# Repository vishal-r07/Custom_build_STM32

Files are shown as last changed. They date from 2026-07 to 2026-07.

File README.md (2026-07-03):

# Customized STM32 Development Board

**Designer:** Vishal Meyyappan R
**Design Tool:** KiCad 9.0
**MCU:** STM32F103C8T6 (LQFP-48)

A compact, breakout-style STM32F103 development board built around a "Blue Pill"-class microcontroller, with dual power input (USB or barrel jack), onboard microSD storage for data logging, and broken-out USART/I2C/SWD headers for peripherals and debugging.

---

## 1. Overview

This board is designed as a general-purpose sensor data acquisition and logging platform. The core idea: read sensor values over I2C or USART, and persist them to a microSD card in real time, so the board can operate as a standalone data logger without needing a permanent connection to a PC. It can be powered either from USB (during development/debugging) or from an external DC supply via the barrel jack (for field/standalone deployment), with both sources safely combined so either one can be present without conflict.

### Key features

- STM32F103C8T6 microcontroller — 72 MHz Cortex-M3, 64KB Flash, 20KB RAM
- Dual power input: USB Micro-B **or** 7–12V DC barrel jack, diode-ORed together
- Onboard AMS1117-3.3 LDO regulator (3.3V logic/power rail)
- microSD card slot (SPI mode) for onboard data storage/logging
- USART1 header for serial communication (e.g. GPS, external logger, PC terminal)
- I2C2 header for sensor peripherals (IMUs, environmental sensors, RTCs, displays, etc.)
- SWD header for programming and debugging (ST-Link compatible)
- Reset button and status LED
- USB D+/D- routed directly to the MCU for native USB device applications (e.g. CDC virtual COM port, DFU bootloader use)
- 4x M2 mounting holes for mechanical enclosure mounting

---

## 2. Functional Blocks

### 2.1 Power Supply

The board accepts power from **either** of two sources, which are combined onto a single protected rail before regulation:

| Source | Connector | Voltage | Notes |
|---|---|---|---|
| USB | J1 (USB Micro-B) | 5V (VBUS) | Also carries D+/D- to the MCU for USB device functionality |
| DC Barrel Jack | J5 | 7–12V (typical wall adapter) | Center pin positive |

Both inputs pass through a dedicated Schottky diode (D2 for the barrel jack, D3 for USB VBUS) before joining onto a common rail. This "power-ORing" arrangement means:
- Either source can be connected and power the board independently.
- If both are connected simultaneously, the board draws from whichever is at the higher potential, without one source backfeeding into the other's connector — protecting a USB host (like a laptop) from being driven by the barrel jack supply, and vice versa.
- Reverse-polarity protection is inherent: if the barrel jack is wired backwards, the diode simply blocks conduction rather than damaging the board.

The combined rail feeds **U2 (AMS1117-3.3)**, a linear regulator that steps the input down to a clean 3.3V rail (`+3.3V`), which powers the MCU core, I/O, and the microSD card. `FB1` (a 120Ω ferrite bead) filters high-frequency noise on the USB VBUS path specifically, and `D1` (LED) with `R3` provides a visual power-on indicator.

A separate `+3.3VA` net is also present for the MCU's analog supply (`VDDA`), isolated with `C7`/`C8` to reduce noise coupling into the ADC/analog peripherals from the digital 3.3V rail.

### 2.2 Microcontroller (U1 — STM32F103C8T6)

The MCU is clocked from an 8 MHz external crystal (`Y1`, `Crystal_GND24`) with `C10`/`C11` (10pF) load capacitors, feeding the HSE (High-Speed External) oscillator input. `SW1` provides a manual reset (NRST), debounced by `C9` and pulled up by `R1`.

Boot mode selection (`BOOT0`) is available on the board for entering the built-in USB/UART bootloader if needed, alongside the SWD interface for hardware debugging.

### 2.3 USB Interface (J1)

A USB Micro-B connector routes `D+`/`D-` directly to the MCU's native USB peripheral pins (`PA11`/`PA12`), enabling USB device applications such as a virtual COM port (CDC), custom HID device, or DFU firmware updates. `R2` (1.5kΩ) pulls `USB_D-` up to 3.3V, a common requirement for the MCU to be recognized as a full-speed USB device without needing to bit-bang the pull-up in firmware.

### 2.4 DC Barrel Jack Input (J5)

For standalone/field operation where USB isn't available (e.g. powered by a wall adapter or battery pack), `J5` accepts a standard center-positive barrel connector. `C14`/`C15` provide bulk and high-frequency decoupling right at the input before the reverse-polarity diode `D2`.

### 2.5 microSD Card Storage (J6)

This is the board's primary logging mechanism. The microSD slot is wired in **SPI mode** (rather than native 4-bit SD mode, which this MCU's hardware doesn't support), using the MCU's SPI1 peripheral:

| J6 Pin | Native SD Function | SPI Mode Function | STM32 Pin |
|---|---|---|---|
| 2 (DAT3/CD) | Data line 3 / Card Detect | Chip Select (CS) | PA4 |
| 3 (CMD) | Command line | MOSI (DI) | PA7 |
| 5 (CLK) | Clock | SCK | PA5 |
| 7 (DAT0) | Data line 0 | MISO (DO) | PA6 |
| 1 (DAT2), 8 (DAT1) | Data lines 1–2 | Unused in SPI mode | Pulled up to 3.3V (R6–R8) |
| 4 (VDD) | Power | Power | +3.3V |
| 6 (VSS) | Ground | Ground | GND |
| 9 (SHIELD) | — | Mechanical shield | GND |

`C16` (100nF) decouples the card's local supply. A pull-up on `CS` (`PA4`) ensures the card remains deselected during MCU power-up/reset, before firmware has configured the pin as an active output — preventing bus contention during boot.

**Intended use case:** the board reads sensor data (e.g. from a device on the I2C2 header) at a fixed interval, formats it (e.g. as a CSV row with a timestamp), and writes it to a file on the SD card using a FAT filesystem library (FatFs) running over this SPI interface. This lets the board function as a self-contained data logger — sensor readings accumulate on the card over time and can be retrieved simply by removing the card and reading it on a PC, without needing a live connection to the board.

### 2.6 Communication Headers

| Header | Signals | Typical Use |
|---|---|---|
| J2 | SWDIO, SWCLK, 3.3V, GND | Programming/debugging via ST-Link or compatible SWD probe |
| J3 | USART1_TX, USART1_RX, 3.3V, GND | Serial communication — external modules (GPS, Bluetooth/BLE, PC terminal), or a second logging path |
| J4 | I2C2_SCL, I2C2_SDA, 3.3V, GND | Sensor peripherals — IMUs, environmental sensors (temperature/humidity/pressure), RTCs, OLED displays, etc. |

`R4`/`R5` (1.5kΩ) provide I2C bus pull-ups on the SDA/SCL lines.

### 2.7 Status & Control

- `D1` (LED) — power-on indicator, active whenever the 3.3V rail is present
- `SW1` — manual reset button (NRST)

### 2.8 Mechanical

Four M2 mounting holes (`H1`–`H4`) are provided at the board corners for enclosure mounting.

---

## 3. Typical Application: Sensor Data Logger

A representative use case this board is designed around:

1. Connect a sensor (e.g. an I2C temperature/humidity sensor, or an IMU) to the **J4 (I2C2)** header.
2. Firmware on the STM32 periodically polls the sensor over I2C.
3. Each reading is timestamped and formatted as a line of text (e.g. CSV: `timestamp,value1,value2`).
4. The line is written to a log file on the microSD card via **SPI1 + FatFs**.
5. The card can be removed and read on any PC, or the board can optionally stream the same data live over **J3 (USART1)** for real-time monitoring during development.

This makes the board suitable for applications like environmental monitoring stations, unattended data collection, portable measurement tools, or any project needing local, non-volatile storage of time-series sensor data without relying on cloud connectivity.

---

## 4. Power Architecture Summary

```
USB Micro-B (5V)  ──▶ D3 ──┐
                            ├──▶ Shared VIN net ──▶ AMS1117-3.3 (U2) ──▶ +3.3V rail ──▶ MCU, SD card, peripherals
Barrel Jack (7-12V) ─▶ D2 ──┘
```

Both sources are diode-ORed so either can power the board independently; the AMS1117-3.3 regulates whichever is present down to a clean 3.3V for the rest of the system.

---

## 5. Bill of Materials

| Reference | Qty | Value | Footprint | Datasheet |
|---|---|---|---|---|
| C1, C2, C3, C4, C9, C15, C16 | 7 | 100n | Capacitor_SMD:C_0402_1005Metric | ~ |
| C5, C14 | 2 | 10u | Capacitor_SMD:C_0603_1608Metric | ~ |
| C6 | 1 | 10n | Capacitor_SMD:C_0402_1005Metric | ~ |
| C7, C8 | 2 | 1u | Capacitor_SMD:C_0402_1005Metric | ~ |
| C10, C11 | 2 | 10p | Capacitor_SMD:C_0402_1005Metric | ~ |
| C12, C13 | 2 | 22u | Capacitor_SMD:C_0805_2012Metric | ~ |
| D1 | 1 | LED | LED_SMD:LED_0603_1608Metric | ~ |
| D2, D3 | 2 | D_Schottky | Diode_SMD:D_SMA | ~ |
| FB1 | 1 | 120R | Inductor_SMD:L_0603_1608Metric | ~ |
| H1, H2, H3, H4 | 4 | MountingHole | MountingHole:MountingHole_2.2mm_M2 | ~ |
| J1 | 1 | USB_B_Micro | Connector_USB:USB_Micro-B_Wuerth_629105150521 | ~ |
| J2, J3, J4 | 3 | Conn_01x04_Pin | Connector_PinSocket_2.54mm:PinSocket_1x04_P2.54mm_Vertical | ~ |
| J5 | 1 | Barrel_Jack | Connector_BarrelJack:BarrelJack_Horizontal | ~ |
| J6 | 1 | Micro_SD_Card | Connector_Card:microSD_HC_Wuerth_693072010801 | [Datasheet](https://www.we-online.com/components/products/datasheet/693072010801.pdf) |
| R1 | 1 | 10K | Resistor_SMD:R_0402_1005Metric | ~ |
| R2, R3, R4, R5 | 4 | 1k5 | Resistor_SMD:R_0402_1005Metric | ~ |
| R6, R7, R8 | 3 | 10k | Resistor_SMD:R_0402_1005Metric | ~ |
| SW1 | 1 | SW_SPDT | Button_Switch_SMD:SW_SPDT_PCM12 | ~ |
| U1 | 1 | STM32F103C8Tx | Package_QFP:LQFP-48_7x7mm_P0.5mm | [Datasheet](https://www.st.com/resource/en/datasheet/stm32f103c8.pdf) |
| U2 | 1 | AMS1117-3.3 | Package_TO_SOT_SMD:SOT-223-3_TabPin2 | [Datasheet](http://www.advanced-monolithic.com/pdf/ds1117.pdf) |
| Y1 | 1 | Crystal_GND24 | Crystal:Crystal_SMD_3225-4Pin_3.2x2.5mm | ~ |

**Total unique references:** 24 | **Total placed components:** ~50 (excluding mounting holes)

---

## 6. Firmware Notes

- **Toolchain:** STM32CubeIDE (or STM32CubeMX + preferred IDE/toolchain)
- **SD card access:** SPI1 peripheral + FatFs middleware (SD-over-SPI driver); recommend low clock speed (~400 kHz) during card initialization, then increasing to a few MHz for normal read/write operations
- **I2C sensor communication:** I2C2 peripheral (`PB10`/`PB11`), 3.3V logic
- **Serial/debug output:** USART1 (`PA9`/`PA10`), standard TTL-level UART, 3.3V logic
- **Debugging:** Standard SWD (`PA13`/`PA14`) — compatible with ST-Link V2/V3 or any SWD-capable probe
- **USB:** Native USB device peripheral (`PA11`/`PA12`) — usable for CDC virtual COM port, custom HID, or DFU bootloader entry

---



**PCB Editor**



**3D VIEW**

I have attached Schematic sheet as output.pdf

---

## Designed by Vishal Meyyappan R

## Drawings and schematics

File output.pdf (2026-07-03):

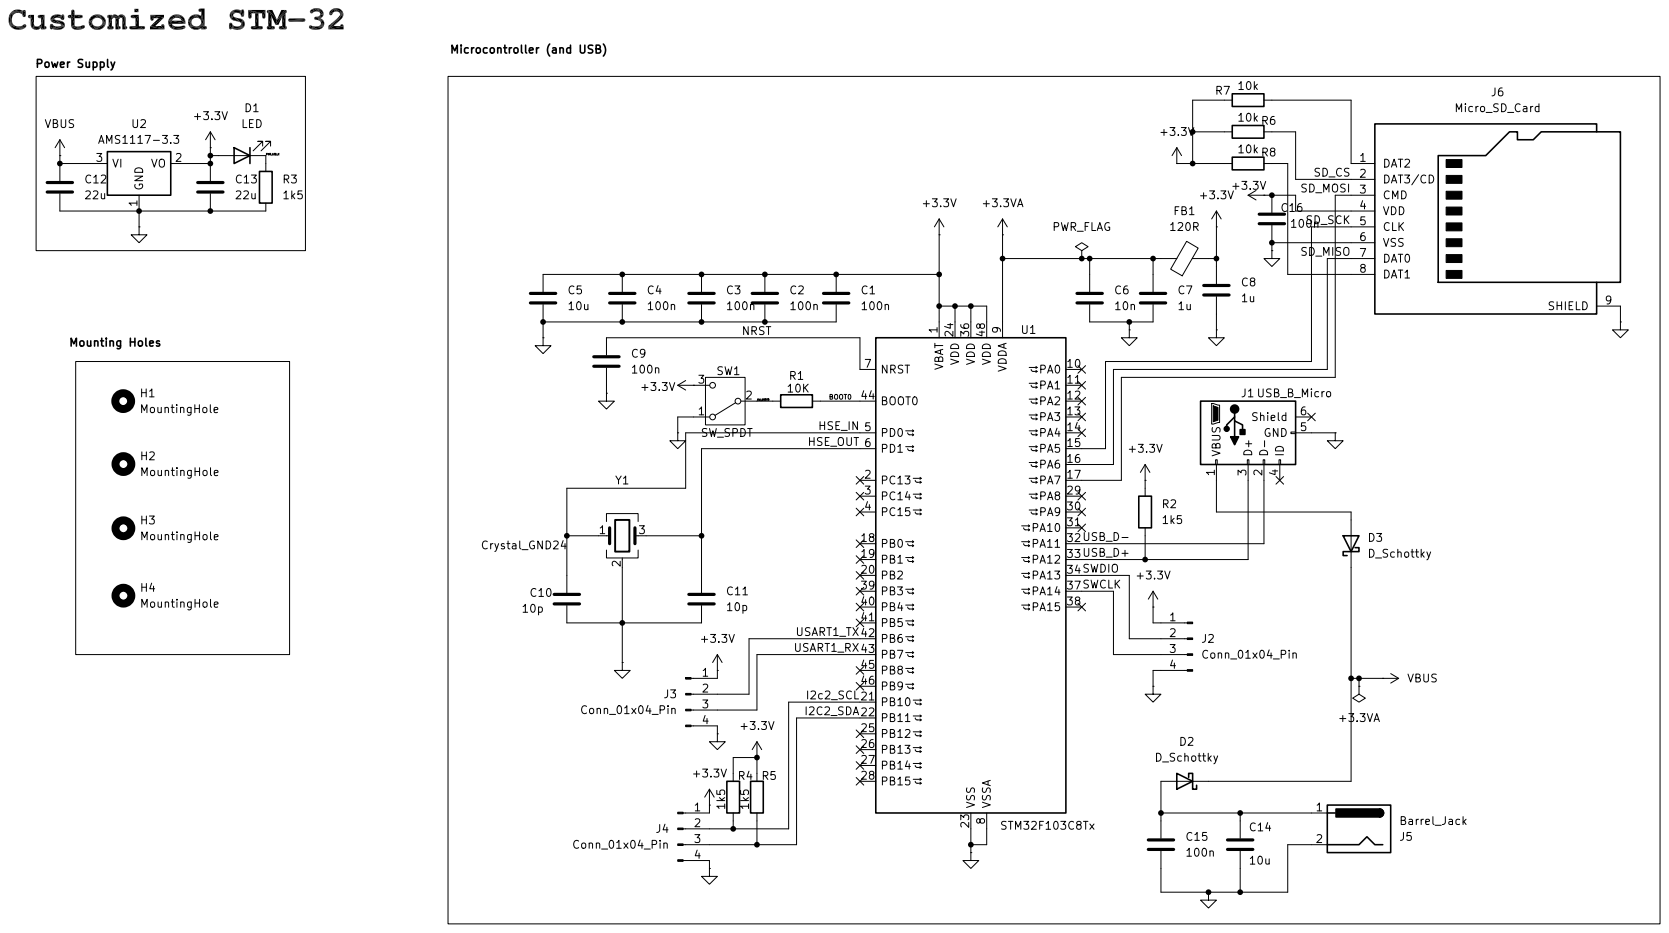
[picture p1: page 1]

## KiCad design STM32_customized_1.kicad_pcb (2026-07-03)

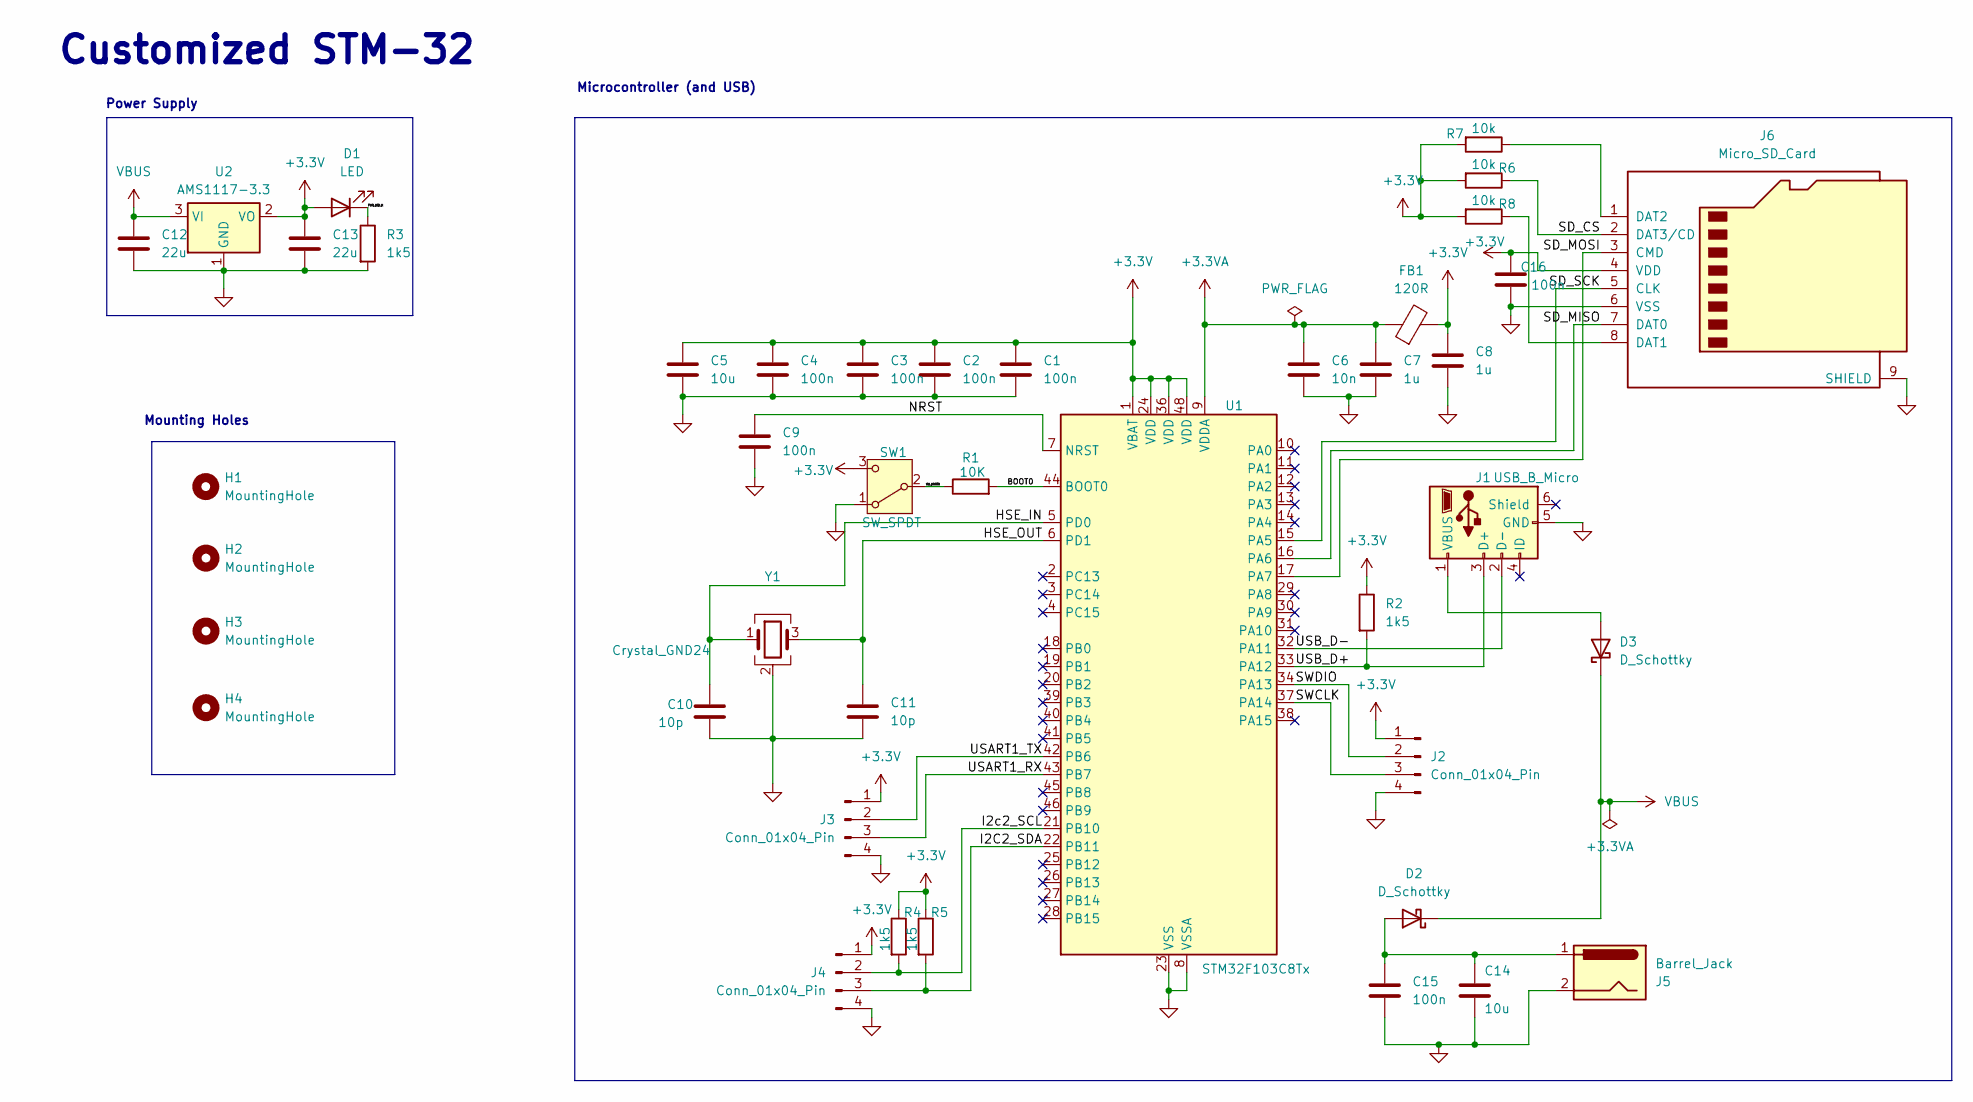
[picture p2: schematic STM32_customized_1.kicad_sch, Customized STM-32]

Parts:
C1, C2, C3, C4, C9, C15, C16: 100n; C_0402_1005Metric
C5, C14: 10u; C_0603_1608Metric
C6: 10n; C_0402_1005Metric
C7, C8: 1u; C_0402_1005Metric
C10, C11: 10p; C_0402_1005Metric
C12, C13: 22u; C_0805_2012Metric
D1: LED; LED_0603_1608Metric
D2, D3: D_Schottky; D_SMA
FB1: 120R; L_0603_1608Metric
H1, H2, H3, H4: MountingHole; MountingHole_2.2mm_M2
J1: USB_B_Micro; USB_Micro-B_Wuerth_629105150521
J2, J3, J4: Conn_01x04_Pin; PinSocket_1x04_P2.54mm_Vertical
J5: Barrel_Jack; BarrelJack_Horizontal
J6: Micro_SD_Card; microSD_HC_Wuerth_693072010801
R1: 10K; R_0402_1005Metric
R2, R3, R4, R5: 1k5; R_0402_1005Metric
R6, R7, R8: 10k; R_0402_1005Metric
SW1: SW_SPDT; SW_SPDT_PCM12
U1: STM32F103C8Tx; LQFP-48_7x7mm_P0.5mm
U2: AMS1117-3.3; SOT-223-3_TabPin2
Y1: Crystal_GND24; Crystal_SMD_3225-4Pin_3.2x2.5mm

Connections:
+3.3V: C1.1, C2.1, C3.1, C4.1, C5.1, C8.1, C13.1, C16.1, D1.2 (A), FB1.2, J2.1, J3.1, J4.1, J6.4 (VDD), R2.1, R4.1, R5.1, R6.2, R7.2, R8.2, SW1.3 (C), U1.1 (VBAT), U1.24 (VDD), U1.36 (VDD), U1.48 (VDD), U2.2 (VO)
+3.3VA: C6.1, C7.1, FB1.1, U1.9 (VDDA)
/BOOT0: R1.2, U1.44 (BOOT0)
/HSE_IN: C10.1, U1.5 (PD0), Y1.1
/HSE_OUT: C11.1, U1.6 (PD1), Y1.3
/I2C2_SDA: J4.3, R5.2, U1.22 (PB11)
/I2c2_SCL: J4.2, R4.2, U1.21 (PB10)
/NRST: C9.1, U1.7 (NRST)
/PWR_LED_K: D1.1 (K), R3.1
/SD_CS: J6.2 (DAT3/CD), R6.1
/SD_MISO: J6.7 (DAT0), U1.16 (PA6)
/SD_MOSI: J6.3 (CMD), U1.17 (PA7)
/SD_SCK: J6.5 (CLK), U1.15 (PA5)
/SWCLK: J2.3, U1.37 (PA14)
/SWDIO: J2.2, U1.34 (PA13)
/SW_BOOT0: R1.1, SW1.2 (B)
/USART1_RX: J3.3, U1.43 (PB7)
/USART1_TX: J3.2, U1.42 (PB6)
/USB_D+: J1.3 (D+), R2.2, U1.33 (PA12)
/USB_D-: J1.2 (D-), U1.32 (PA11)
GND: C1.2, C2.2, C3.2, C4.2, C5.2, C6.2, C7.2, C8.2, C9.2, C10.2, C11.2, C12.2, C13.2, C14.2, C15.2, C16.2, J1.5 (GND), J2.4, J3.4, J4.4, J5.2, J6.6 (VSS), J6.9 (SHIELD), R3.2, SW1.1 (A), U1.8 (VSSA), U1.23 (VSS), U1.35 (VSS), U1.47 (VSS), U2.1 (GND), Y1.2 (G), Y1.4 (G)
unnamed: C14.1, C15.1, D2.2 (A), J5.1
unnamed: D3.2 (A), J1.1 (VBUS)
unnamed: J6.8 (DAT1), R8.1
unnamed: J6.1 (DAT2), R7.1
VBUS: C12.1, D2.1 (K), D3.1 (K), U2.3 (VI)

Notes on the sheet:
Mounting Holes
Microcontroller (and USB)
Power Supply
Customized STM-32

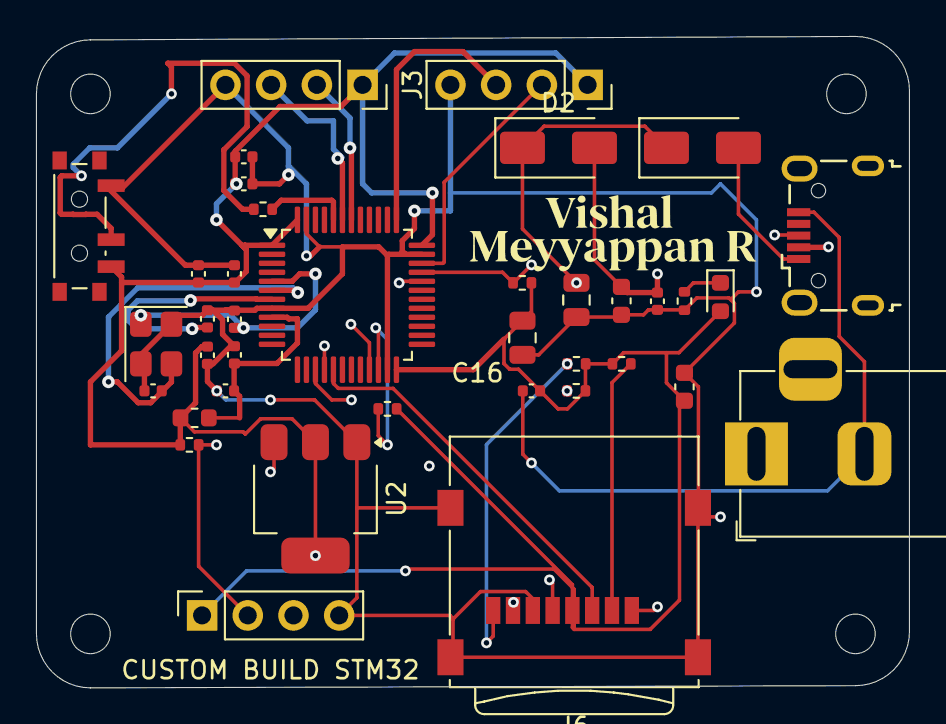
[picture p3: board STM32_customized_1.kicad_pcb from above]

Board: 4 copper layers, 48.5 x 36.2 mm, 42 parts (0 on the bottom side), 26 nets.

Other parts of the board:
CUSTOM BUILD STM32: MountingHole; MountingHole_2.2mm_M2

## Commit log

2026-07-03 Enhance README with functional specifications and guides
    Expanded the README to include detailed functional specifications, application guides, and implementation workflows for the customized STM32F103C8Tx development board.
2026-07-03 Revise README for improved documentation and clarity
    Updated the README to enhance clarity and structure, including sections on features, functional blocks, power architecture, and firmware notes.
2026-07-03 Schematic is uploaded
2026-07-03 Update README with PCB editor and 3D view images
    Added images and updated information about PCB editor and 3D view.
